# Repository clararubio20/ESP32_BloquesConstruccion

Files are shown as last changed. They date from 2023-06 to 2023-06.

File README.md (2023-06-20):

# Casa domótica con ESP32 compatible con LEGO y controlada por servidor web

## 🧱 Resumen
En este repositorio se encuentra la aplicación completa para la creación de una casa domótica compatible con piezas LEGO y controlada por la placa ESP32. Este programa está pensado para niños/as de edades en torno a 14 años, supervisados por profesores o tutores que quieran transmitir conocimiento básicos de electrónica y concienciación medioambiental. Se pueden controlar los diferentes componentes por medio de una web que el microcontrolador envía al ordenador. Para ello, se han diseñado e impreso piezas 3D que encajen con cada uno de los componentes que se usen (disponibles en la carpeta de modelos 3D y en https://www.thingiverse.com/thing:6082576).

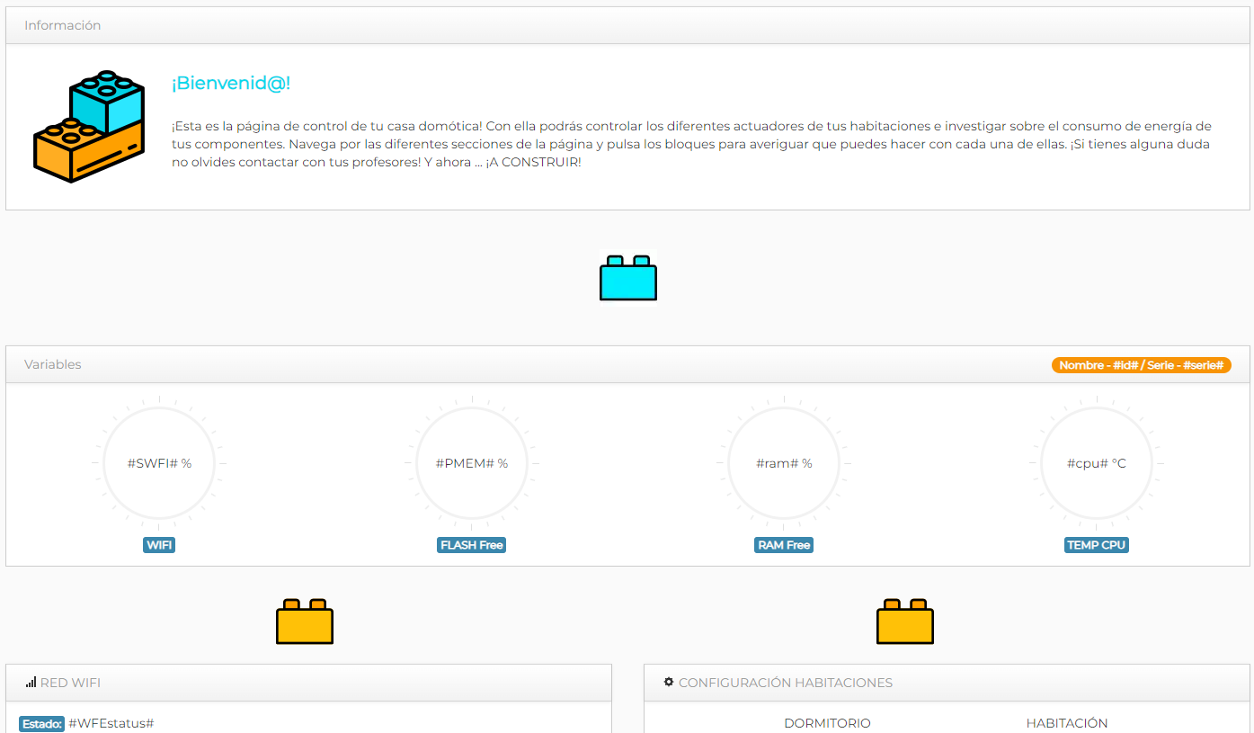
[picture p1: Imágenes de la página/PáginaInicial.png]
Página de la aplicación


Para la creación de esta página se ha utilizado la plantilla disponible en https://github.com/yamir84/esp32_admin_html .

## 🧱 Qué se necesita 

+ PMicrocontrolador ESP32 con WiFi.
+ Dispositivo de compilación y carga del programa (ordenador).
+ 2 sensores infrarrojos OKY3127 (típicos para Arduino).
+ 2 fotorresistencias de 5 mm + 2 resistencias de 10 kΩ.
+ 2 LED de 5 mm de diámetro + 2 resistencias de 220 Ω.

## 🧱 Instalación
1. Se requiere la instalación del Visual Studio Code ( https://code.visualstudio.com/docs/setup/windows ) y de la herramienta PlatformIO ( https://platformio.org/install/ide?install=vscode ).
2. Una vez instalado el SW, se debe descargar el proyecto disponible en el repositorio. Pulsar el menú extensible Code y hacer click en Download ZIP.
3. Se importa el proyecto pulsando "Import Arduino Project" en la interfaz de PlatformIO y se elige el proyecto y la placa "DOIT ESP32 DEVKIT V1".
4. En las líneas 39 y 40 del archivo main.cpp de la carpeta src, se deben poner los pines en los que se van a conectar los sensores y actuadores posteriormente. Para ello, se debe tener en cuenta el orden en que se mandan los datos en los argumentos de la función. Si se eliminan estas líneas, el sistema adjudica valores por defecto en el archivo ClaseDormitorio.h y ClaseHabitacion.h.
5. En la función configReset() del archivo Config.h (carpeta include), se deben poner el nombre y contraseña de la red WiFi disponible, así como una contraseña para el punto de acceso WiFi que la ESP32 crea. Los nuevos valores deben sustituir a los nombres entre comillas.
6. Para cargar los archivos de la carpeta data, se debe pulsar la herramienta Upload Filesystem Image de PlatformIO (pulsando su ícono a la izquierda salen todas las opciones del programa).
7. Se compila el proyecto.
8. Se conectan los componentes de la siguiente forma:
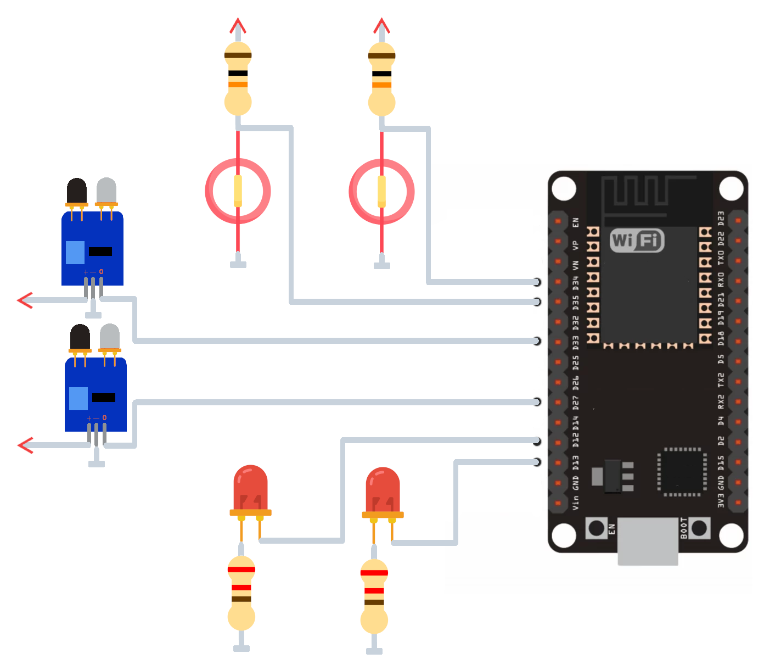
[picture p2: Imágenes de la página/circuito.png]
Circuito de la aplicación

10. Se carga el proyecto en la placa y se abre el puerto serie. Si se han puesto las credenciales de la red WiFi correctamente, debería aparecer la dirección IP del WiFi (número de 12 dígitos separado por puntos).
11. Se este número y pega en la barra de búsqueda del navegador.
12. ¡El programa ya está listo para ser usado!

## 🧱 Uso
En el video https://www.youtube.com/watch?v=L1hvOIxlgWg se muestra el uso que se le puede dar a la aplicación. ¡Pregunta cualquier duda o interacciona con la comunidad!

## 🧱 Autoría

Este proyecto ha sido realizado por Clara Rubio Almagro para el Trabajo Fin de Grado de Ingeniería de Sistemas Electrónicos de la Universidad de Málaga, bajo la supervisión de Cristina Urdiales García.

## 🧱 Licencia
Este proyecto está licenciado bajo la Licencia GPU. Consulte el archivo LICENSE para obtener más información.

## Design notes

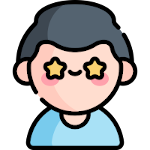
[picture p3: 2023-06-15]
Imágenes de la página/entusiasmado.png

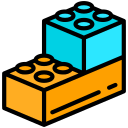
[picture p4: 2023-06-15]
Imágenes de la página/legos.png

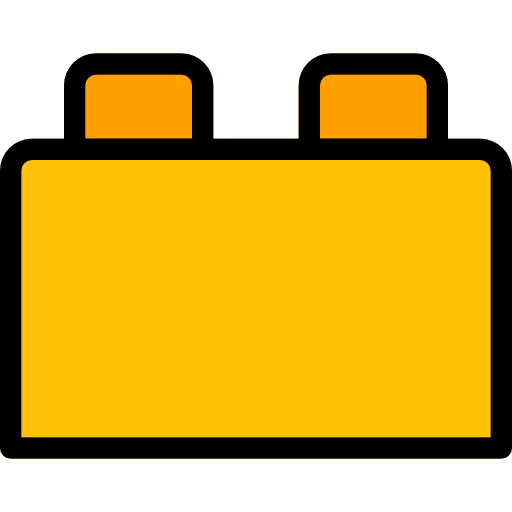
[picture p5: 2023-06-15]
Imágenes de la página/lego.png

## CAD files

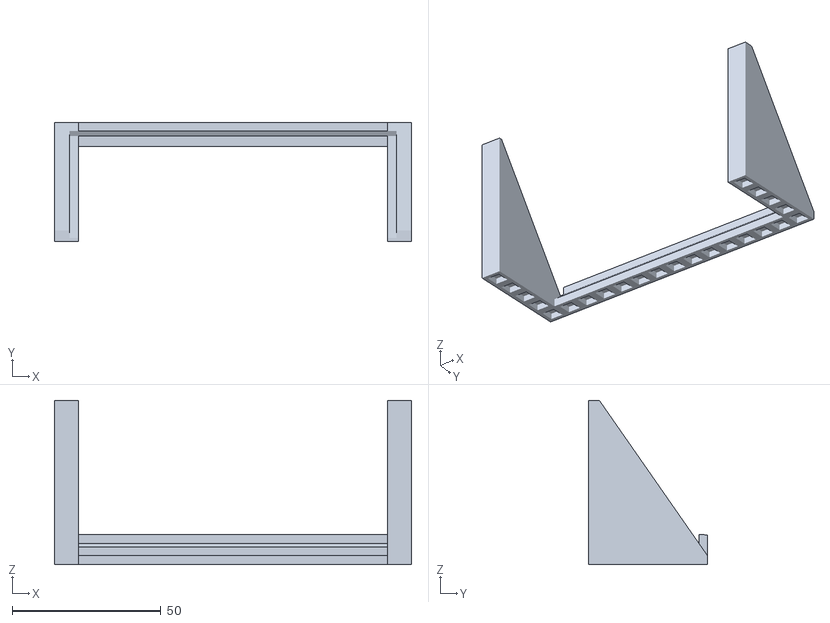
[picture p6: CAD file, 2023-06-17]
Modelos 3D/solar.stl
120.0 x 40.0 x 55.2

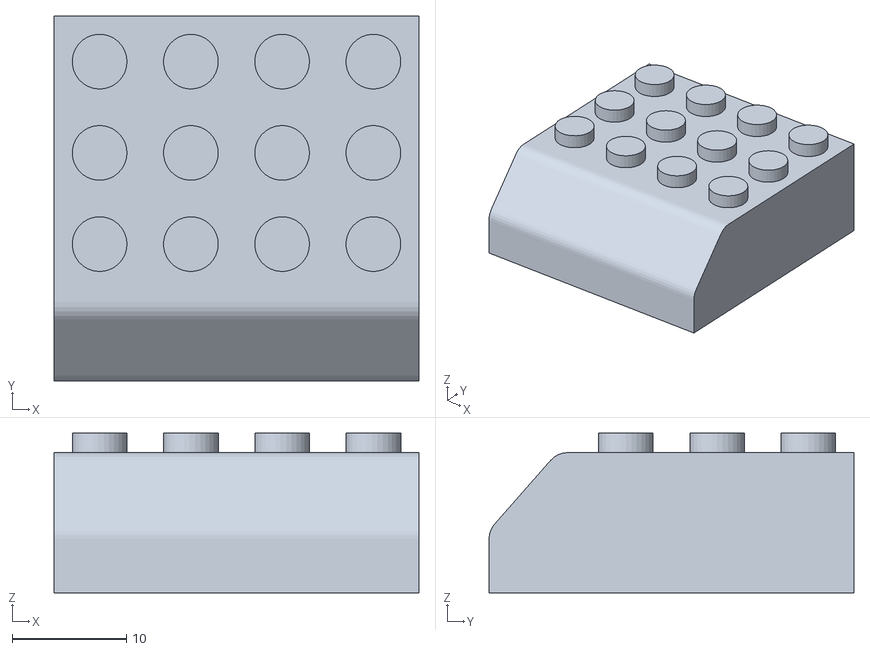
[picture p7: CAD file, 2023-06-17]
Modelos 3D/tapaCable_4x4.stl
32.0 x 32.0 x 14.0

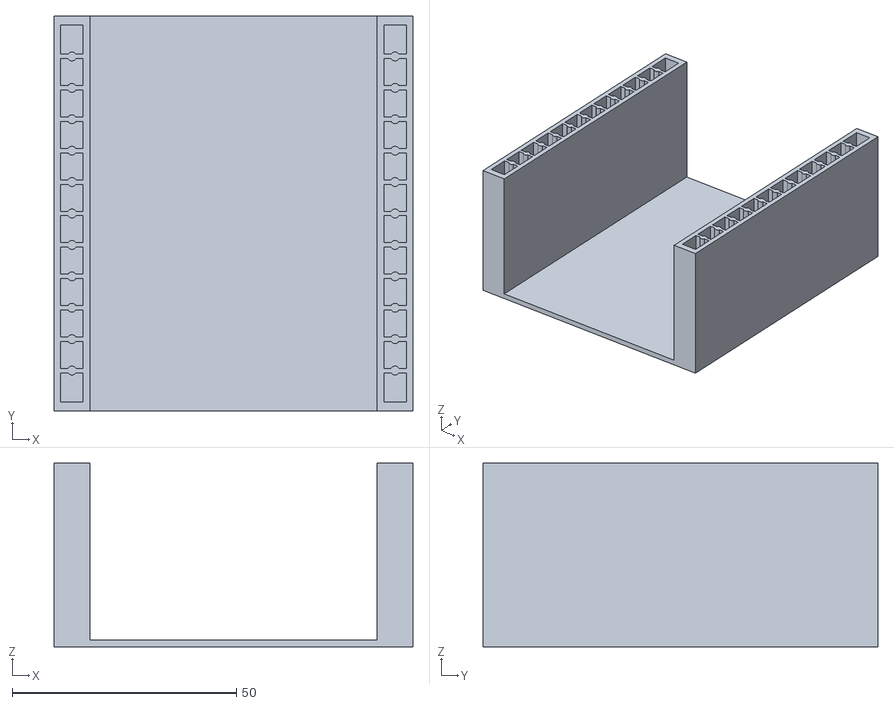
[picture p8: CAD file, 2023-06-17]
Modelos 3D/tapaPro.stl
80.0 x 88.0 x 41.0

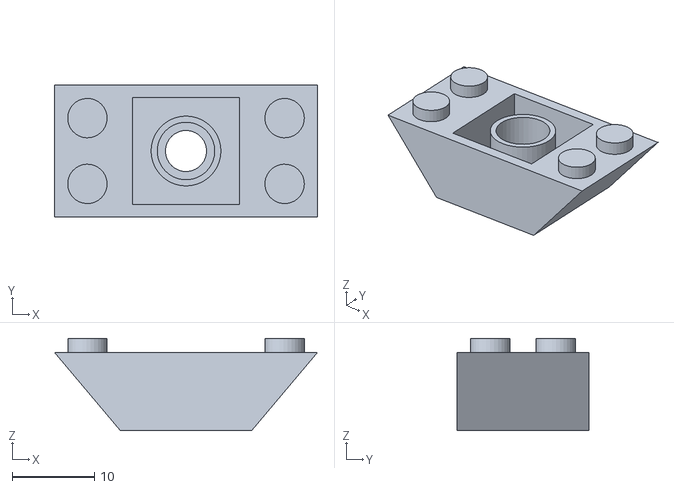
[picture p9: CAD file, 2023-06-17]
Modelos 3D/LED_4x2.stl
32.0 x 16.0 x 11.2

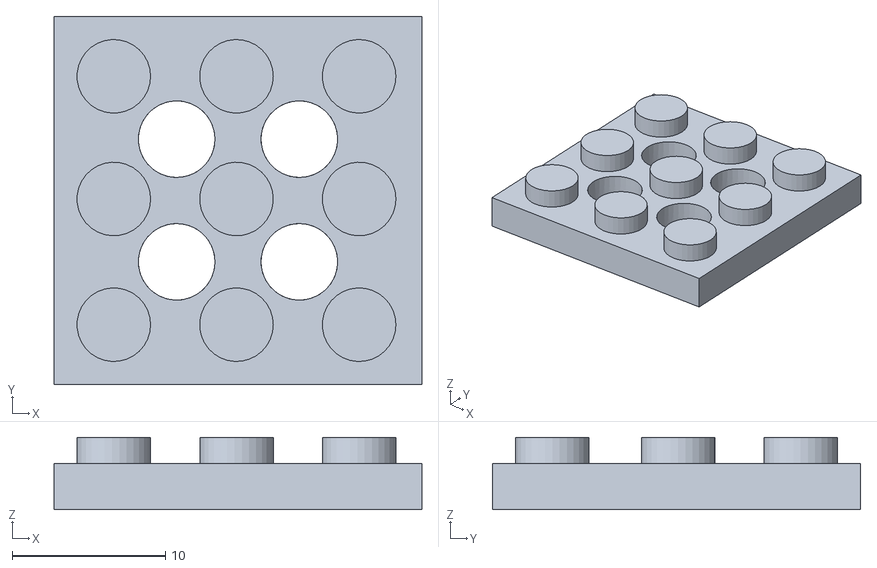
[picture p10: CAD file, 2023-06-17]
Modelos 3D/hueco_4_3x3.stl
24.0 x 24.0 x 4.70

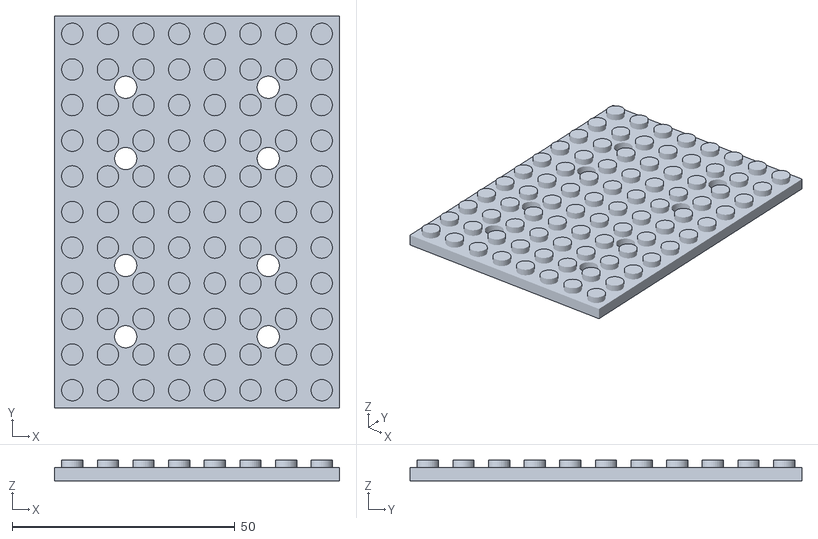
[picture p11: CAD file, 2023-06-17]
Modelos 3D/hueco_8_11x8.stl
64.0 x 88.0 x 4.70

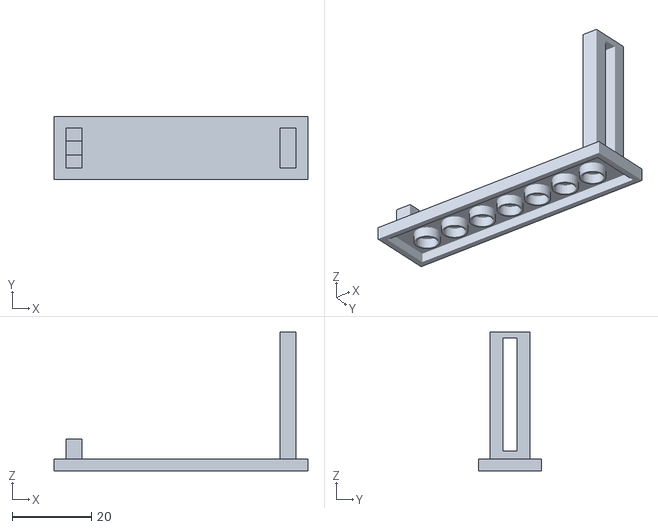
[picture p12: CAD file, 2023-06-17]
Modelos 3D/ESP32.stl
64.0 x 16.0 x 35.0

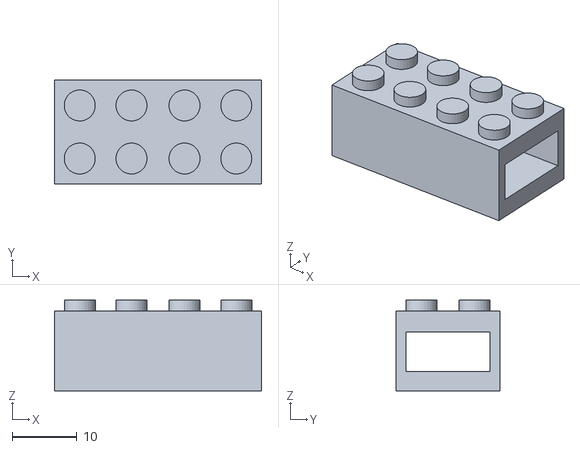
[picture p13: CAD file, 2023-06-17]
Modelos 3D/cable_4x2.stl
32.0 x 16.0 x 14.0

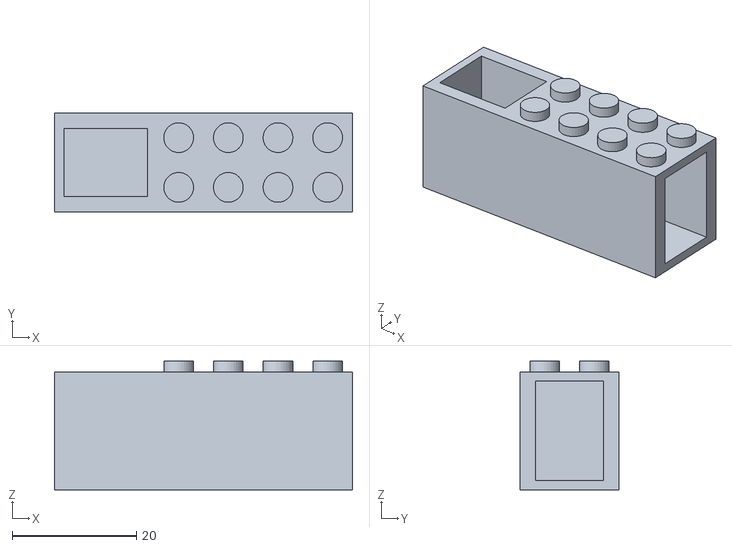
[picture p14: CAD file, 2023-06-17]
Modelos 3D/Infrarrojo.stl
48.0 x 16.0 x 20.7

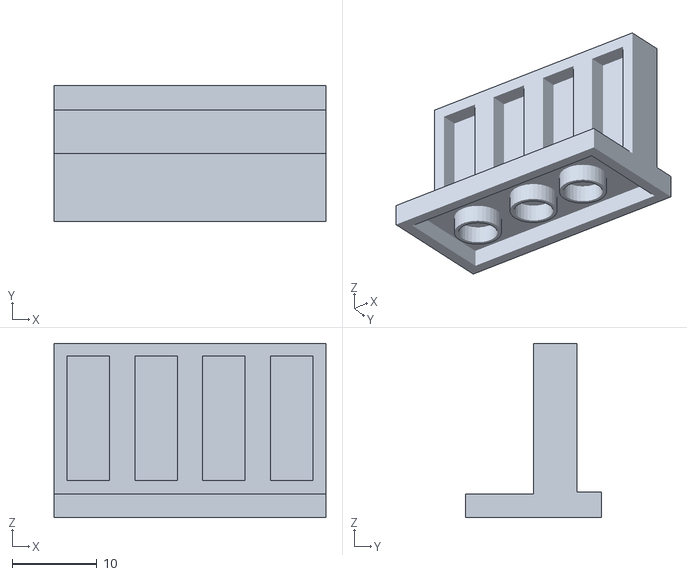
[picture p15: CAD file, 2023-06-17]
Modelos 3D/adaptador_4x2.stl
32.0 x 16.0 x 20.5

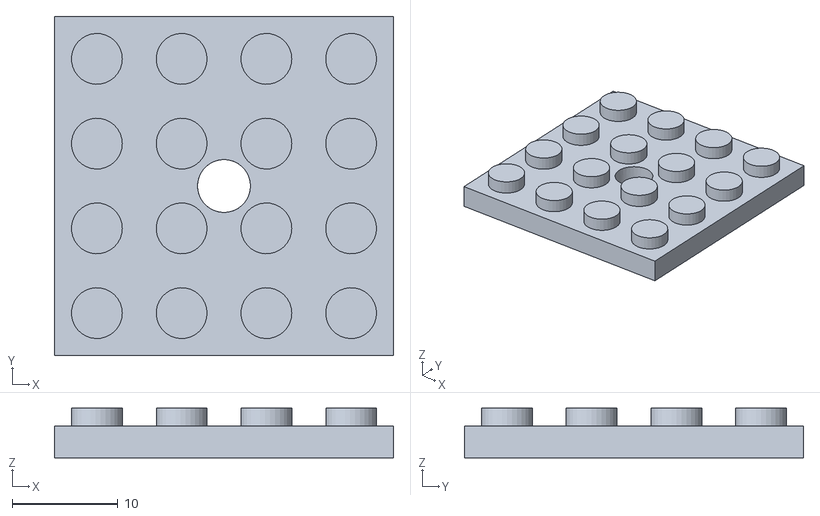
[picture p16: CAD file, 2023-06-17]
Modelos 3D/hueco_1_4x4.stl
32.0 x 32.0 x 4.70

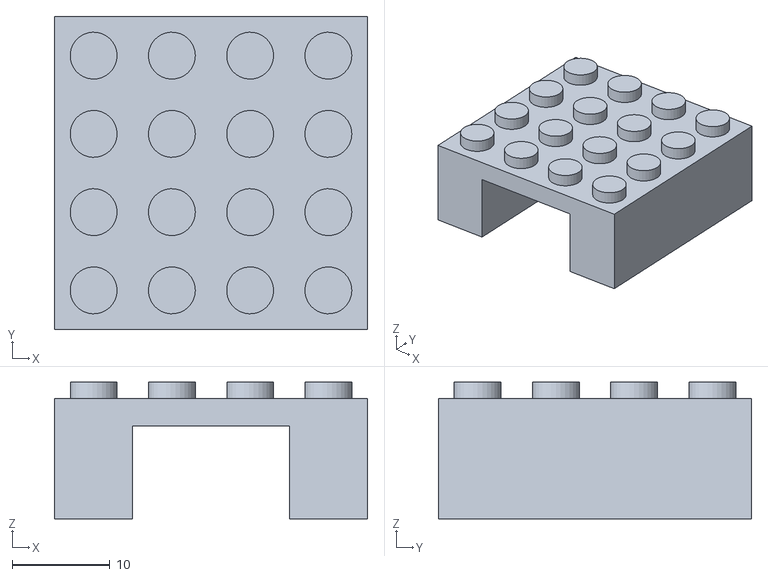
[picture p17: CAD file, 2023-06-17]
Modelos 3D/cable_4x4.stl
32.0 x 32.0 x 14.0

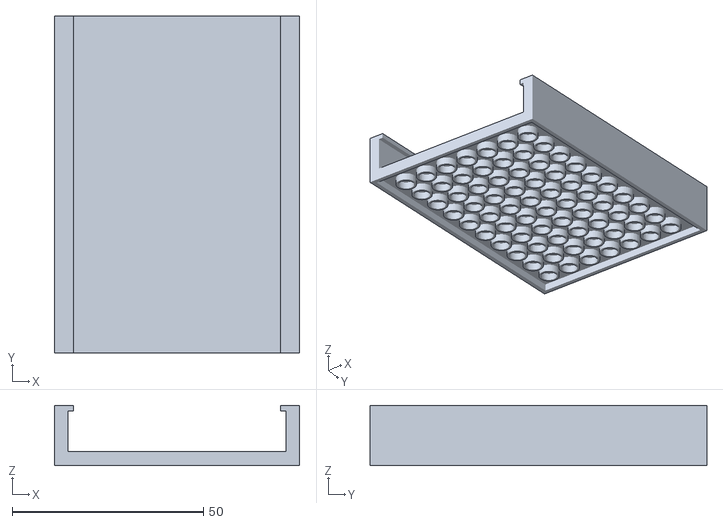
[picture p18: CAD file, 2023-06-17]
Modelos 3D/capaPro.stl
64.0 x 88.0 x 15.7

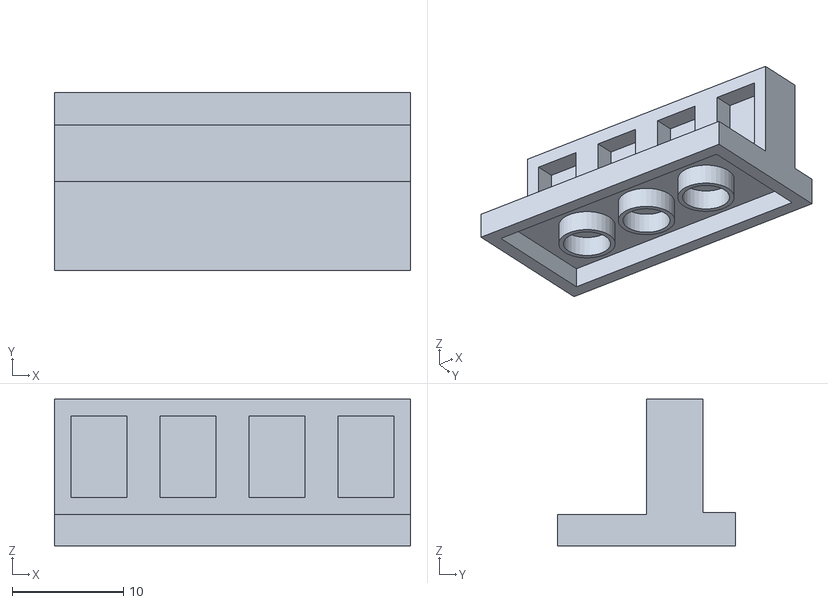
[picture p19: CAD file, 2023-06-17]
Modelos 3D/adaptador4x2x1.stl
32.0 x 16.0 x 13.2

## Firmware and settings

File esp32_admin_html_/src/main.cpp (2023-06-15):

/*
* Archivo creado por: Clara Rubio Almagro
* Fecha de la ultima modificación: 15/06/2023
* Trabajo Fin de Grado
* Titulación: Sistemas electrónicos
* Universidad de Málaga
*/

/* LIBRERIAS */
#include <Arduino.h>
#include <WiFi.h>
#include <SPIFFS.h>              // Para guardar archivos en la RAM
#include <ArduinoJson.h>         // Formato de mensajes que se van a enviar
#include <AsyncTCP.h>            // Uso de websockets
#include <ESPAsyncWebServer.h>   // Servidor web
#include "esp32-hal-cpu.h"       // Para obtener datos de la ESP32
#include <DNSServer.h>

/* ARCHIVOS DEL PROYECTO */
#include "ClaseDormitorio.h"
#include "ClaseHabitacion.h"
#include "header.hpp"
#include "functions.hpp"
#include "Config.hpp"
#include "ESP32_WIFI.hpp"
#include "Server.hpp"
#include "ESP32_API.hpp"         
#include "Websocket.hpp"
#include "ESP32_WS.hpp"

void setup() 
{
  /* VELOCIDAD DEL PUERTO SERIE */
  Serial.begin(115200);
  /* FRECUENCIA DE LA CPU (VELOCIDAD DEL MICRO) */
  setCpuFrequencyMhz(240);
  log("\nInfo:Iniciando Setup");
  /* CONFIGURACIÓN DE LAS HABITACIONES */
  dormitorio1.configuracionInicial(12, 27, 35, 50, '0','0','0', 0);
  habitacion1.configuracionInicial(13, 33, 34, 50, '0','0', 0);
  /* CONFIGURACIÓN PINES */
  configPines();
  /* SPIFFS */
  if (!SPIFFS.begin(true))
  {
    log("\nError: Fallo la inicialización del SPIFFS ERROR");
    while (true);
  }
  /* LECTURA CONFIGURACIÓN */
  configRead();
  /* GUARDADO CONFIGURACIÓN */
  configSave();
  /* CONFIGURACIÓN WIFI */
  WiFi.disconnect(true);
  delay(1000);
  WiFi.onEvent(WiFiStationDisconnected, WiFiEvent_t::ARDUINO_EVENT_WIFI_STA_DISCONNECTED);
  configWiFi();
  /* INICIO WEBSOCKET */
  InitWebSockets();
  /* INICIO SERVIDOR */
  InitServer();
  log("\nInfo: Setup completado");
}

void loop() {
  /* PROCESADOR DE PETICIONES DE LA WEB */
  dnsServer.processNextRequest();
  /* ENVÍO DE MENSAJES CADA SEGUNDO */
  if (millis() - lastSendWS > 1000){
      lastSendWS  = millis();
      WsMessage(GetJson(), "");
  }
  /* LECTURA TEMPERATURA CPU */
  TempCPU = (temprature_sens_read() - 32) / 1.8;
  /* LECTURA SENSORES INFRARROJOS */
  int valueINFR = 0;
  // Dormitorio
  valueINFR = digitalRead(dormitorio1.leerPinIFR());
  if (valueINFR == LOW) {
      dormitorio1.cambiarEstadoPresencia('1');
  }
  else{
    dormitorio1.cambiarEstadoPresencia('0');
  }
  // Habitacion
  valueINFR = digitalRead(habitacion1.leerPinIFR() );
  if (valueINFR == LOW) {
      habitacion1.cambiarEstadoPresencia('1');
  }
  else{
    habitacion1.cambiarEstadoPresencia('0');
  }
  /* LECTURA LDR */
  dormitorio1.cambiarLuz(map(analogRead(dormitorio1.leerPinLDR()), 4095 , 0, 0 ,100));
  habitacion1.cambiarLuz(map(analogRead(habitacion1.leerPinLDR()), 4095 , 0, 0 ,100));
  /* MÁQUINA DE ESTADOS */
  if (modo == true)
  {
    // Gestión individual de las habitaciones
    dormitorio();
    habitacion();
  }
}

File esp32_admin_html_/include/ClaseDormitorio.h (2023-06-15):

/*
* Archivo creado por: Clara Rubio Almagro
* Fecha de la ultima modificación: 15/06/2023
* Trabajo Fin de Grado
* Titulación: Sistemas electrónicos
* Universidad de Málaga
*/

class ClaseDormitorio
{
    private:
        unsigned int pinLED, pinIFR, pinLDR, luzAdec;
        char estadoLED, estadoPresencia, esNoche;
        float luz;
    public:
        ClaseDormitorio();
        ~ClaseDormitorio();
        void configuracionInicial(unsigned int pLED,unsigned int pIFR,unsigned int pLDR, unsigned int luzA, char estLED, char estPresencia, char Noche, float l);
        void configPines();
        void encederLED();
        void apagarLED();
        void cambiarEstadoLED(char estado);
        void cambiarEstadoPresencia(char estado);
        void cambiarHorario(char estado);
        void cambiarLuz(float l);
        void cambiarLuzAdec(unsigned int l);
        unsigned int leerLuzAdec();
        float leerLuz();
        char leerEstadoLED();
        char leerEstadoPresencia();
        char leerHorario();
        unsigned int leerPinLDR();
        unsigned int leerPinIFR();
};

ClaseDormitorio::ClaseDormitorio()
{
    pinLED = 12;
    pinIFR = 27;
    pinLDR = 35;
    luzAdec = 50;
    estadoLED = '0';
    estadoPresencia = '0';
    esNoche = '0';
    luz = 0;
}

ClaseDormitorio::~ClaseDormitorio(){}

void ClaseDormitorio::configuracionInicial(unsigned int pLED,unsigned int pIFR,unsigned int pLDR, unsigned int luzA, char estLED, char estPresencia, char Noche,  float l)
{
    pinLED = pLED;
    pinIFR = pIFR;
    pinLDR = pLDR;
    luzAdec = luzA;
    estadoLED = estLED;
    estadoPresencia = estPresencia;
    luz = l;
    esNoche = Noche;
}

void ClaseDormitorio::configPines()
{
    pinMode(pinLED, OUTPUT);
    pinMode(pinIFR, INPUT);
    pinMode(pinLDR, INPUT);
}

void ClaseDormitorio::encederLED()
{
    digitalWrite(pinLED, HIGH);
    estadoLED = '1';
}

void ClaseDormitorio::apagarLED()
{
    digitalWrite(pinLED, LOW);
    estadoLED = '0';
}

void ClaseDormitorio::cambiarEstadoLED(char estado)
{
    estadoLED = estado;
}

void ClaseDormitorio::cambiarEstadoPresencia(char estado)
{
    estadoPresencia = estado;
}

void ClaseDormitorio::cambiarHorario(char estado)
{
    esNoche = estado;
}

void ClaseDormitorio::cambiarLuz(float l)
{
    luz = l;
}

void ClaseDormitorio::cambiarLuzAdec(unsigned int l)
{
    luzAdec = l;
}

unsigned int ClaseDormitorio::leerLuzAdec()
{
    return luzAdec;
}

float ClaseDormitorio::leerLuz()
{
    return luz;
}

char ClaseDormitorio::leerEstadoLED()
{
    return estadoLED;
}

char ClaseDormitorio::leerEstadoPresencia()
{
    return estadoPresencia;
}

char ClaseDormitorio::leerHorario()
{
    return esNoche;
}

unsigned int ClaseDormitorio::leerPinLDR()
{
    return pinLDR;
}

unsigned int ClaseDormitorio::leerPinIFR()
{
    return pinIFR;
}

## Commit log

2023-06-15 Subida de aplicación
2023-06-15 Subida de imágenes del personaje
2023-06-15 subida de iconos de legos
2023-06-15 escritura de las atribuciones
